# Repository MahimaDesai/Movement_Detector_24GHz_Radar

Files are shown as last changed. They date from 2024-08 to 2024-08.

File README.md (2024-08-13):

# Movement_Detector_24GHz_Radar
A 24 GHz radar sensor detects movements and sends detected signal to bandpass filter.
The 4th order Bandpass filter gives amplified signal as the output which in-turn is sent to the ADC.
PSOC calculates FFT of ADC data and sends it to MATLAB.
CFAR is used to set a threshold with which the probability of false alarm reduced.

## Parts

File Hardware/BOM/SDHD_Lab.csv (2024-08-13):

Reference | Value | Datasheet | Footprint | Qty | DNP
C1 | 22u | ~ | Capacitor_THT:CP_Radial_D5.0mm_P2.50mm | 1
C2,C5 | 4.7u | ~ | Capacitor_THT:CP_Radial_D6.3mm_P2.50mm | 2
C3 | 1.5n | ~ | Capacitor_THT:C_Rect_L7.2mm_W7.2mm_P5.00mm_FKS2_FKP2_MKS2_MKP2 | 1
C4 | 100n | ~ | Capacitor_THT:C_Rect_L7.2mm_W2.5mm_P5.00mm_FKS2_FKP2_MKS2_MKP2 | 1
C6 | 3.3n | ~ | Capacitor_THT:C_Rect_L7.2mm_W7.2mm_P5.00mm_FKS2_FKP2_MKS2_MKP2 | 1
D1 | Green_Led | ~ | LED_THT:LED_D5.0mm | 1
D2 | Orange_Led | ~ | LED_THT:LED_D5.0mm | 1
D3 | Red_Led | ~ | LED_THT:LED_D5.0mm | 1
D4 | Power_Led | ~ | LED_THT:LED_D5.0mm | 1
J1 | +5V_Test | ~ | Connector_PinHeader_2.54mm:PinHeader_1x01_P2.54mm_Vertical | 1
J2 | GND_Test1 | ~ | Connector_PinHeader_2.54mm:PinHeader_1x01_P2.54mm_Vertical | 1
J3 | GND_Test3 | ~ | Connector_PinHeader_2.54mm:PinHeader_1x01_P2.54mm_Vertical | 1
J4 | GND_Test2 | ~ | Connector_PinHeader_2.54mm:PinHeader_1x01_P2.54mm_Vertical | 1
J5 | VDI_Test | ~ | Connector_PinHeader_2.54mm:PinHeader_1x01_P2.54mm_Vertical | 1
J6 | IN1 | ~ | Connector_PinHeader_2.54mm:PinHeader_1x01_P2.54mm_Vertical | 1
J7 | IN2 | ~ | Connector_PinHeader_2.54mm:PinHeader_1x01_P2.54mm_Vertical | 1
J8 | OUT1 | ~ | Connector_PinHeader_2.54mm:PinHeader_1x01_P2.54mm_Vertical | 1
J9 | IN3 | ~ | Connector_PinHeader_2.54mm:PinHeader_1x01_P2.54mm_Vertical | 1
J10 | OUT2 | ~ | Connector_PinHeader_2.54mm:PinHeader_1x01_P2.54mm_Vertical | 1
J11 | Vout | ~ | Connector_PinHeader_2.54mm:PinHeader_1x01_P2.54mm_Vertical | 1
J12 | Radar Module Pins | ~ | Connector_PinSocket_2.54mm:PinSocket_1x03_P2.54mm_Horizontal | 1
P1 | Power | ~ | Connector_PinHeader_2.54mm:PinHeader_1x08_P2.54mm_Vertical | 1
P2,P4 | Digital/PWM | ~ | -- mixed values -- | 2
P3 | Analog | ~ | Connector_PinHeader_2.54mm:PinHeader_1x06_P2.54mm_Vertical | 1
R1,R2 | 1k | ~ | Resistor_THT:R_Axial_DIN0207_L6.3mm_D2.5mm_P10.16mm_Horizontal | 2
R3,R4,R6,R8 | 470 | ~ | Resistor_THT:R_Axial_DIN0207_L6.3mm_D2.5mm_P10.16mm_Horizontal | 4
R5 | 2.2K | ~ | Resistor_THT:R_Axial_DIN0207_L6.3mm_D2.5mm_P10.16mm_Horizontal | 1
R7 | 220K | ~ | Resistor_THT:R_Axial_DIN0207_L6.3mm_D2.5mm_P10.16mm_Horizontal | 1
R9 | 10k | ~ | Resistor_THT:R_Axial_DIN0207_L6.3mm_D2.5mm_P10.16mm_Horizontal | 1
R10 | 33.3K | ~ | Resistor_THT:R_Axial_DIN0207_L6.3mm_D2.5mm_P10.16mm_Horizontal | 1
R11 | 100K | ~ | Resistor_THT:R_Axial_DIN0207_L6.3mm_D2.5mm_P10.16mm_Horizontal | 1
R12 | 100 | ~ | Resistor_THT:R_Axial_DIN0207_L6.3mm_D2.5mm_P10.16mm_Horizontal | 1
SW1 | SW_Push | ~ | Button_Switch_THT:SW_PUSH_6mm_H7.3mm | 1
U1,U2 | OPA340P | http://www.ti.com/lit/ds/symlink/opa340.pdf | Package_DIP:DIP-8_W7.62mm | 2

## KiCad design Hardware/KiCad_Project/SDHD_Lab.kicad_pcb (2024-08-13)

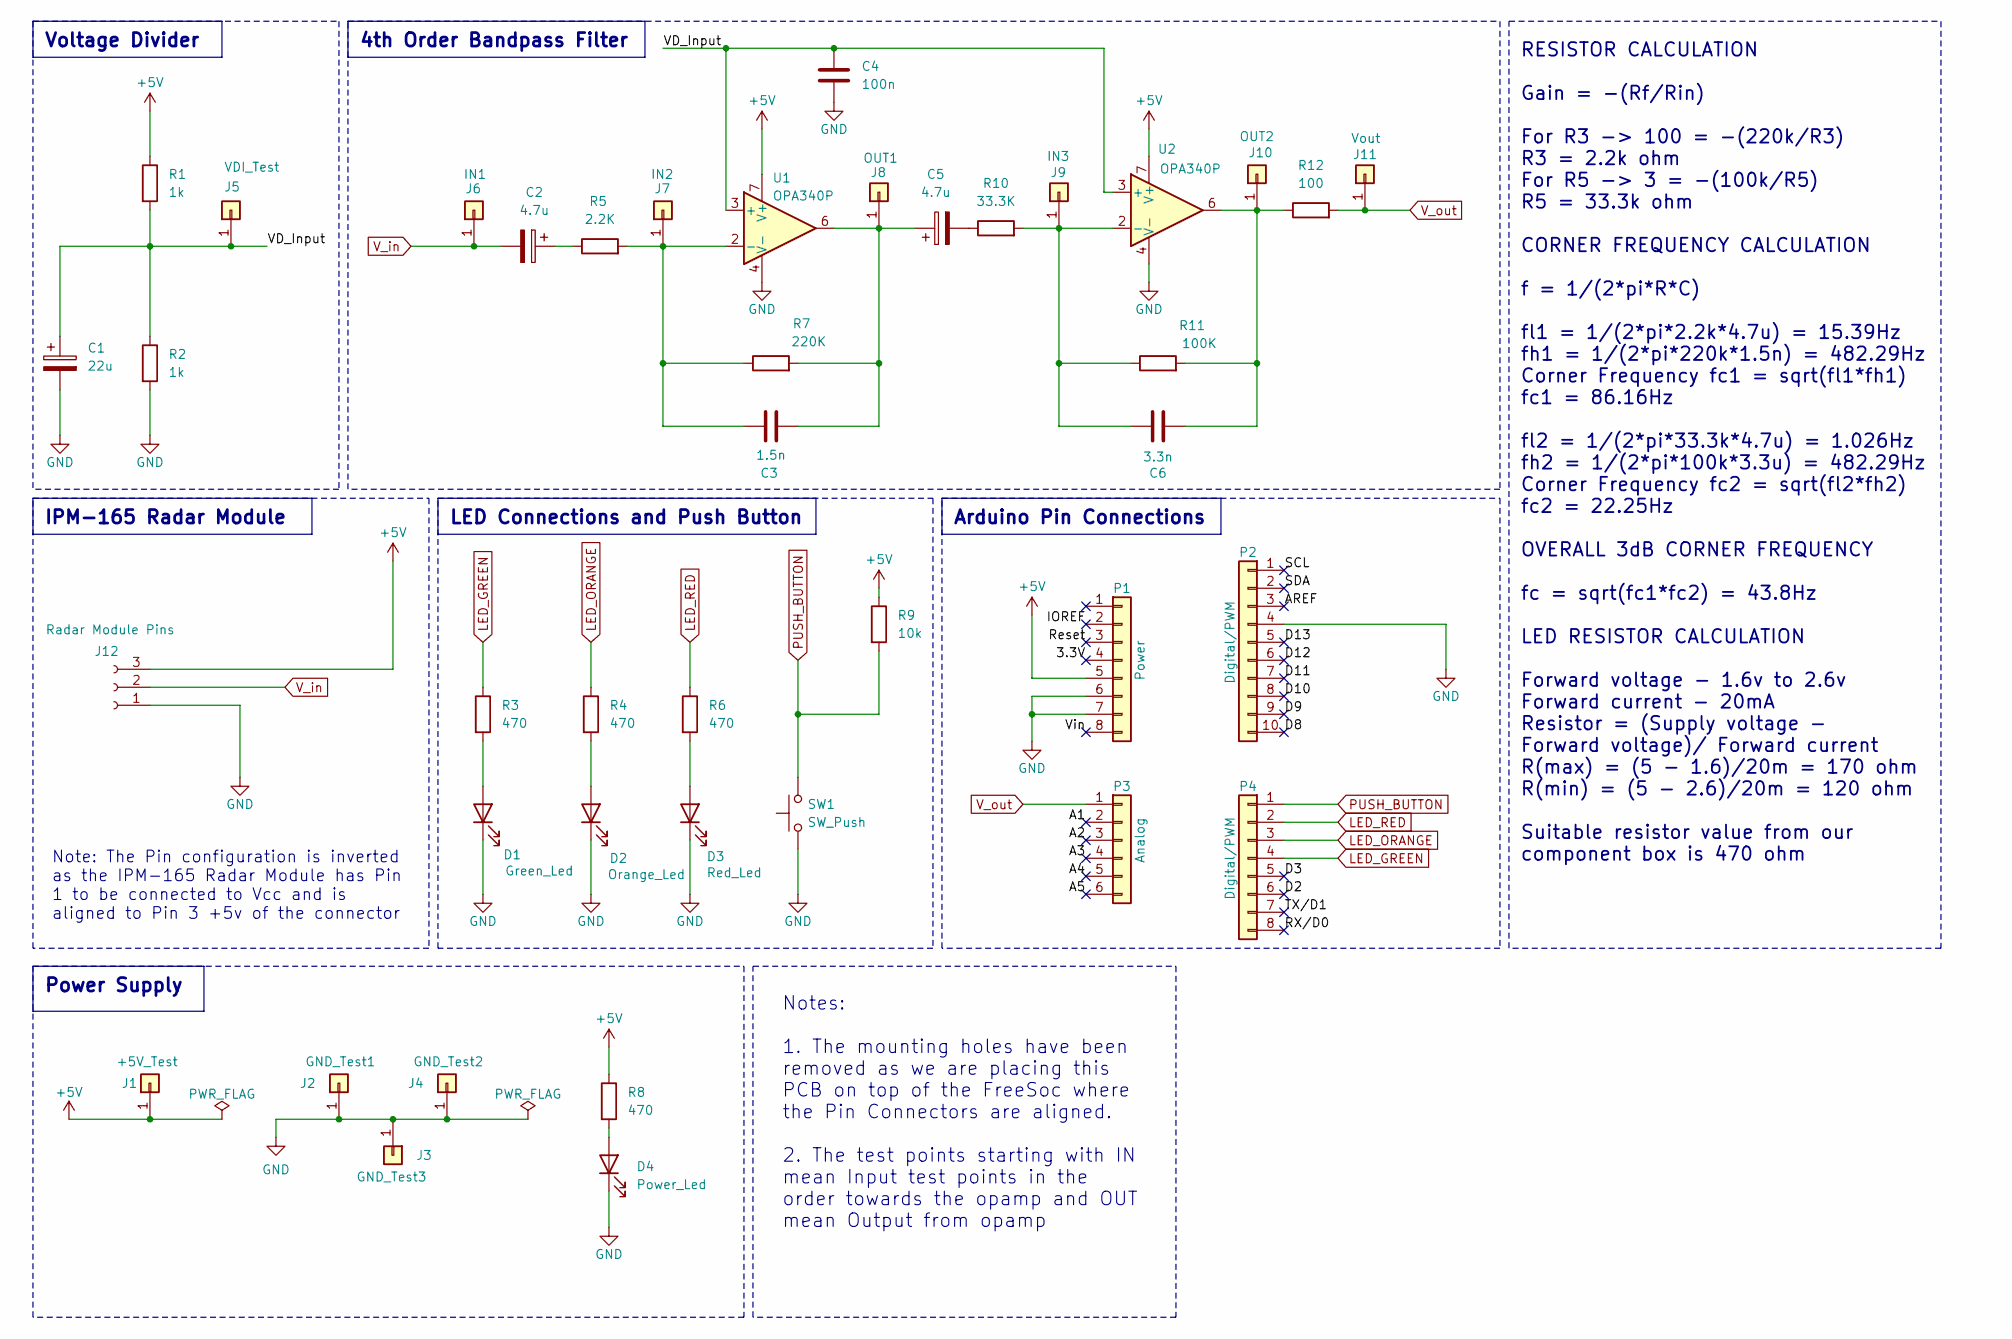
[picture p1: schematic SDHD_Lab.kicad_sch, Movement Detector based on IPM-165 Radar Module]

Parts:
C1: 22u; CP_Radial_D5.0mm_P2.50mm
C2, C5: 4.7u; CP_Radial_D6.3mm_P2.50mm
C3: 1.5n; C_Rect_L7.2mm_W7.2mm_P5.00mm_FKS2_FKP2_MKS2_MKP2
C4: 100n; C_Rect_L7.2mm_W2.5mm_P5.00mm_FKS2_FKP2_MKS2_MKP2
C6: 3.3n; C_Rect_L7.2mm_W7.2mm_P5.00mm_FKS2_FKP2_MKS2_MKP2
D1: Green_Led; LED_D5.0mm
D2: Orange_Led; LED_D5.0mm
D3: Red_Led; LED_D5.0mm
D4: Power_Led; LED_D5.0mm
J1: +5V_Test; PinHeader_1x01_P2.54mm_Vertical
J2: GND_Test1; PinHeader_1x01_P2.54mm_Vertical
J3: GND_Test3; PinHeader_1x01_P2.54mm_Vertical
J4: GND_Test2; PinHeader_1x01_P2.54mm_Vertical
J5: VDI_Test; PinHeader_1x01_P2.54mm_Vertical
J6: IN1; PinHeader_1x01_P2.54mm_Vertical
J7: IN2; PinHeader_1x01_P2.54mm_Vertical
J8: OUT1; PinHeader_1x01_P2.54mm_Vertical
J9: IN3; PinHeader_1x01_P2.54mm_Vertical
J10: OUT2; PinHeader_1x01_P2.54mm_Vertical
J11: Vout; PinHeader_1x01_P2.54mm_Vertical
J12: Radar Module Pins; PinSocket_1x03_P2.54mm_Horizontal
P1: Power; PinHeader_1x08_P2.54mm_Vertical
P2: Digital/PWM; PinHeader_1x10_P2.54mm_Vertical
P3: Analog; PinHeader_1x06_P2.54mm_Vertical
P4: Digital/PWM; PinHeader_1x08_P2.54mm_Vertical
R1, R2: 1k; R_Axial_DIN0207_L6.3mm_D2.5mm_P10.16mm_Horizontal
R3, R4, R6, R8: 470; R_Axial_DIN0207_L6.3mm_D2.5mm_P10.16mm_Horizontal
R5: 2.2K; R_Axial_DIN0207_L6.3mm_D2.5mm_P10.16mm_Horizontal
R7: 220K; R_Axial_DIN0207_L6.3mm_D2.5mm_P10.16mm_Horizontal
R9: 10k; R_Axial_DIN0207_L6.3mm_D2.5mm_P10.16mm_Horizontal
R10: 33.3K; R_Axial_DIN0207_L6.3mm_D2.5mm_P10.16mm_Horizontal
R11: 100K; R_Axial_DIN0207_L6.3mm_D2.5mm_P10.16mm_Horizontal
R12: 100; R_Axial_DIN0207_L6.3mm_D2.5mm_P10.16mm_Horizontal
SW1: SW_Push; SW_PUSH_6mm_H7.3mm
U1, U2: OPA340P; DIP-8_W7.62mm

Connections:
+5V: J1.1, J12.3, P1.5, R1.1, R8.1, R9.1, U1.7 (V+), U2.7 (V+)
/3.3V: P1.4
/A1: P3.2
/A2: P3.3
/A3: P3.4
/A4: P3.5
/A5: P3.6
/AREF: P2.3
/D2: P4.6
/D3: P4.5
/D8: P2.10
/D9: P2.9
/D10: P2.8
/D11: P2.7
/D12: P2.6
/D13: P2.5
/IOREF: P1.2
/RX/D0: P4.8
/Reset: P1.3
/SCL: P2.1
/SDA: P2.2
/TX/D1: P4.7
/VD_Input: C1.1, C4.1, J5.1, R1.2, R2.1, U1.3 (+), U2.3 (+)
/Vin: P1.8
GND: C1.2, C4.2, D1.1 (K), D2.1 (K), D3.1 (K), D4.1 (K), J2.1, J3.1, J4.1, J12.1, P1.6, P1.7, P2.4, R2.2, SW1.1, U1.4 (V-), U2.4 (V-)
LED_GREEN: P4.4, R3.1
LED_ORANGE: P4.3, R4.1
LED_RED: P4.2, R6.1
unnamed: C2.1, R5.1
unnamed: C5.2, R10.1
unnamed: D1.2 (A), R3.2
unnamed: D2.2 (A), R4.2
unnamed: D3.2 (A), R6.2
unnamed: D4.2 (A), R8.2
unnamed 34: C3.1, J7.1, R5.2, R7.1, U1.2 (-); also elsewhere on the board
unnamed 35: C3.2, C5.1, J8.1, R7.2, U1.6; also elsewhere on the board
unnamed: C6.1, J9.1, R10.2, R11.1, U2.2 (-)
unnamed: C6.2, J10.1, R11.2, R12.1, U2.6
PUSH_BUTTON: P4.1, R9.2, SW1.2
V_in: C2.2, J6.1, J12.2
V_out: J11.1, P3.1, R12.2

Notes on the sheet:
Power Supply
4th Order Bandpass Filter
IPM-165 Radar Module
LED Connections and Push Button
Voltage Divider
Note: The Pin configuration is inverted as the IPM-165 Radar Module has Pin 1 to be connected to Vcc and is aligned to Pin 3 +5v of the connector
Notes: 1. The mounting holes have been removed as we are placing this PCB on top of the FreeSoc where the Pin Connectors are aligned. 2. The test points starting with IN mean Input test points in the order towards the opamp and OUT mean Output from opamp
Arduino Pin Connections
RESISTOR CALCULATION Gain = -(Rf/Rin) For R3 -> 100 = -(220k/R3) R3 = 2.2k ohm For R5 -> 3 = -(100k/R5) R5 = 33.3k ohm CORNER FREQUENCY CALCULATION f = 1/(2*pi*R*C) fl1 = 1/(2*pi*2.2k*4.7u) = 15.39Hz fh1 = 1/(2*pi*220k*1.5n) = 482.29Hz Corner Frequency fc1 = sqrt(fl1*fh1) fc1 = 86.16Hz fl2 = 1/(2*p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

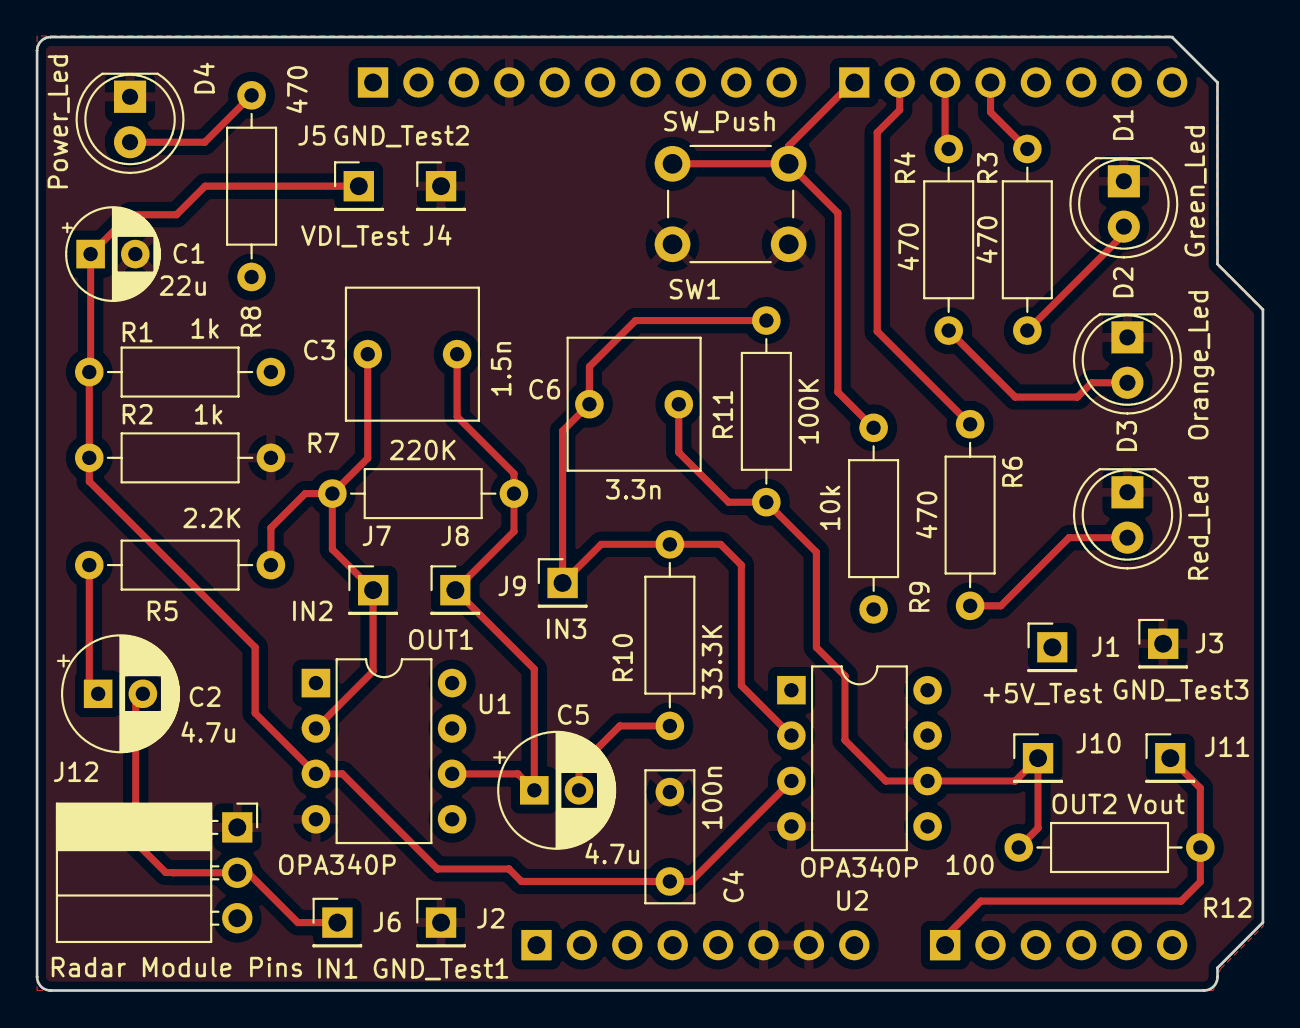
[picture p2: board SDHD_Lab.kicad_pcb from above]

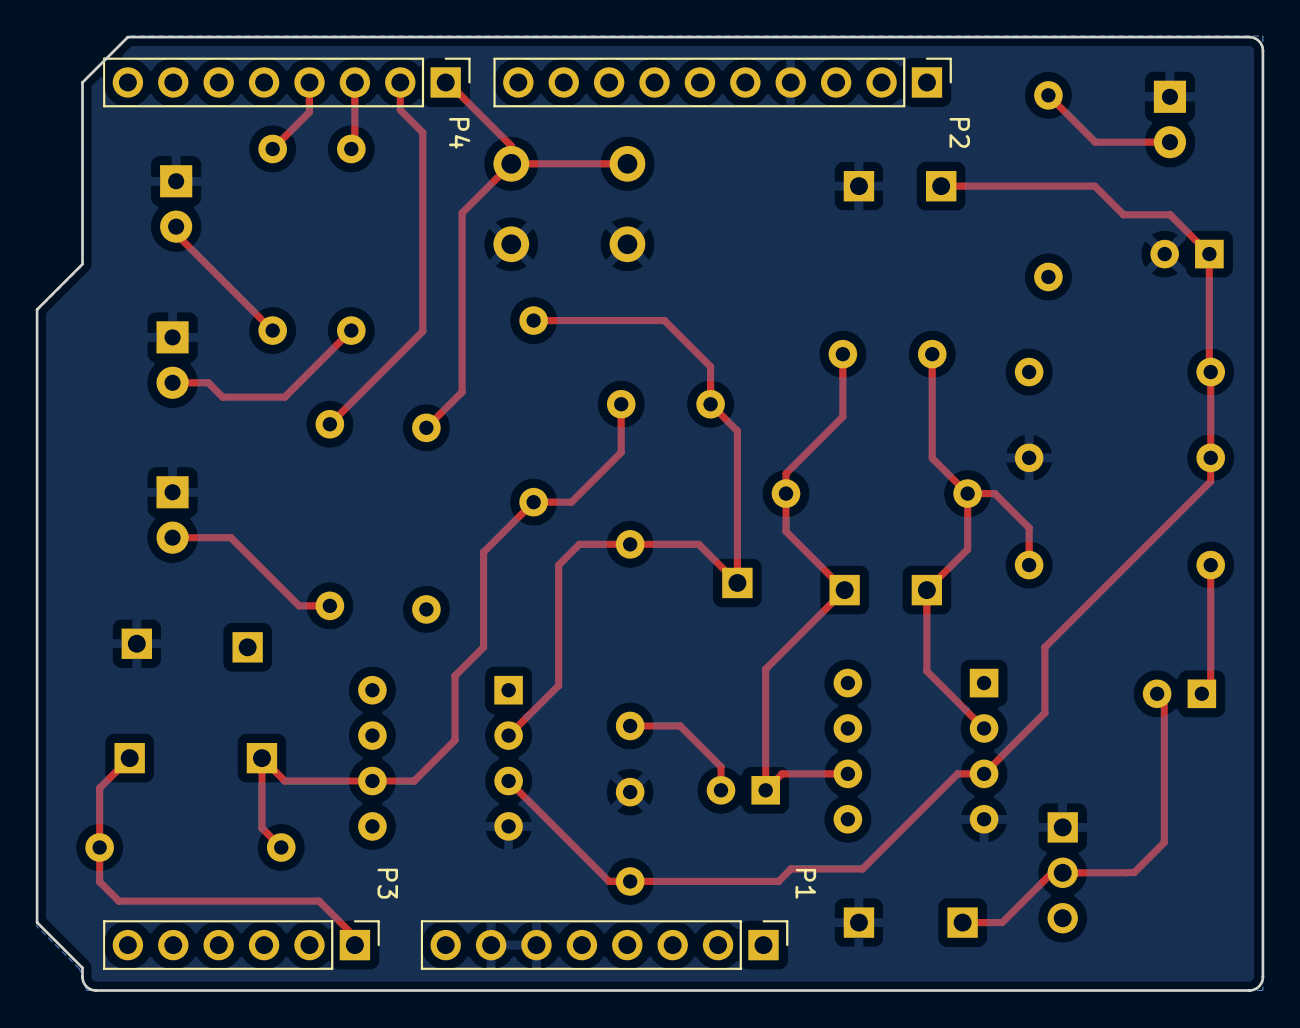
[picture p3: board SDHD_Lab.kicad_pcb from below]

Board: 4 copper layers, 68.6 x 53.3 mm, 41 parts (4 on the bottom side), 19 nets.

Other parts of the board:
R7 : 220K; R_Axial_DIN0207_L6.3mm_D2.5mm_P10.16mm_Horizontal

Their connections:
unnamed 34: R7.1; also elsewhere on the board
unnamed 35: R7.2; also elsewhere on the board

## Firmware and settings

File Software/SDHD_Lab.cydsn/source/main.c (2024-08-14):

/* ========================================
 *
 * Copyright YOUR COMPANY, THE YEAR
 * All Rights Reserved
 * UNPUBLISHED, LICENSED SOFTWARE.
 *
 * CONFIDENTIAL AND PROPRIETARY INFORMATION
 * WHICH IS THE PROPERTY OF your company.
 *
 * ========================================
*/

#include "project.h"
#include "fft_application.h"

// ISR declarations
CY_ISR_PROTO(isr_button_RisingEdge_Interrupt);
CY_ISR_PROTO(isr_UART);

// Enum for state machine states
typedef enum
{
    IDLE_STATE,
    SAMPLING_STATE,
    UART_TRANSFER_STATE

}STATE_t;

// State machine function declaration
void stateMachine();

// Variable declarations
volatile uint8 button_pressed = 0; // Push button status
uint8_t sReceived = 0; // status of s character recieved 
uint8_t oReceived = 0; // status of o character recieved
char RxMatlab; // Character recieved from MATLAB
uint8_t count = 0; // Transfer count
uint16_t ADC_Array[1024] = {0}; // Array to store ADC data
STATE_t state = IDLE_STATE; // State machine state initialization
int32 FFT_SamplesArray[2 * 1024] = {0}; // Array to store FFT samples

int main(void)
{
    CyGlobalIntEnable; /* Enable global interrupts. */
    
    isr_button_StartEx(isr_button_RisingEdge_Interrupt);
    isr_UART_StartEx(isr_UART);
    
    //Hardware Init
    UART_Start();
    WaveDAC_Start();
    ADC_Start();
    ADC_StartConvert();
    
    for(;;)
    {
        stateMachine();
    }
}

void stateMachine()
{
    switch(state)
    {
        case IDLE_STATE:
            count = 0;
            // Handle LED states
            Red_LED_Write(1);
            Yellow_LED_Write(0);     
            Green_LED_Write(0);
            
            if(button_pressed == 1)
            {
                // Setting state to SAMPLING_STATE when button is pressed
                state = SAMPLING_STATE;
                button_pressed = 0;               
            }
        break;
            
        case SAMPLING_STATE:
            // Handle LED states
            Red_LED_Write(0);
            Yellow_LED_Write(1);     
            Green_LED_Write(0);
            // ADC conversion and storing data in array
            for(int i = 0; i < 1024; i++)
            {
                ADC_IsEndConversion(ADC_WAIT_FOR_RESULT);                  
                ADC_Array[i] = (uint16_t)ADC_GetResult32();
            }
            // Setting state to UART_TRANSFER_STATE if 's' received from MATLAB
            if(sReceived)
            {             
                state = UART_TRANSFER_STATE;
                sReceived = 0;
            }
        break;
            
        case UART_TRANSFER_STATE:
            // Handle LED states
            Red_LED_Write(0);
            Yellow_LED_Write(0);     
            Green_LED_Write(1);
            // Transfer ADC data to MATLAB
            for(int i = 0; i < 1024; i++)
            {
                UART_PutChar(ADC_Array[i]);
                UART_PutChar(ADC_Array[i]>>8);
            }
            // FFT calculation of ADC data
            fft_app(ADC_Array,FFT_SamplesArray,1024);
            
            // Transfer FFT data to MATLAB
            for(int32 idx = 0; idx < 2048; idx++)
            {
                UART_PutChar(FFT_SamplesArray[idx]);
                UART_PutChar(FFT_SamplesArray[idx]>>8);
                UART_PutChar(FFT_SamplesArray[idx]>>16);
                UART_PutChar(FFT_SamplesArray[idx]>>24);
            }
            // Increment count
            count++;                
            
            // Move to next transfer if count < 10
            if((count < 10) && oReceived)
            {
                state = SAMPLING_STATE;
                oReceived = 0;
            }
            // Setting state to IDLE_STATE when count is 10
            else if((count == 10) && oReceived)
            {
                // Handle LED states
                Red_LED_Write(0);
                Yellow_LED_Write(0);     
                Green_LED_Write(0);
                state = IDLE_STATE;  
                oReceived = 0;
            }
            else // Stay in same state
            {
                state = UART_TRANSFER_STATE;  
                oReceived = 0; 
            }
        break;
            
        default:
        break;
    }   
}

    
CY_ISR(isr_button_RisingEdge_Interrupt)
{
    // Update button_pressed variable based on push button
    Push_button_ClearInterrupt();
    
    if(button_pressed == 0)
    {
        button_pressed = 1;
    }
}

CY_ISR(isr_UART)
{
    // Set character flags based on character received from MATLAB
    RxMatlab = UART_GetChar();
    if(RxMatlab == 's')
    {
        sReceived = 1;
    }
    if(RxMatlab == 'o')
    {
        oReceived = 1;
    }
}
/* [] END OF FILE */
